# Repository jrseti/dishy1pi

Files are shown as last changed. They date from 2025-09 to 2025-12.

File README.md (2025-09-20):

# dishy1pi
Satellite dish motor control for Raspberry Pi, hardware and software

This project was developed in Windows 11 with Python 3.12.

## Prerequisites

It is suggested to create a Python3 virtual environment for this project. Here is how:

- From the project root directory "python3 -m venv venv"
- .\venv\Scripts\activate (Note: this command will be a bit different on Linux or MacOS)

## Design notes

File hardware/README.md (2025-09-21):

# Hardware Projects for Dishy1Pi

This directory contains hardware projects and designs related to the Dishy1Pi, a Raspberry Pi Hat tocontrol motors and encoders for a satellite dish.

## Projects

- **Dishy1Pi**: The main project, a Raspberry Pi Hat designed to control motors and encoders for a satellite dish. It includes schematics, PCB layouts, and bill of materials (BOM).

- **power-supply**: A project focused on designing a power supply unit for the Dishy1Pi, ensuring it can provide the necessary voltage and current for operation.

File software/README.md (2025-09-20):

# Software for the Dish Controller

Nothing here yet. This will be the source code of the software that runs on the RaspberryPi Hat. Probably a mixture of C and Python.

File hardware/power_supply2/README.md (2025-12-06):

# Power Supply circuit based on the MP2322 Buck Chip
This is a simple PCB to test creating several voltages that are used on the Dishy1Pi PCB. Once this cirction is tested as working, the relevant schematic parts will be moved over to the DishyPi1 schematic. The voltages needed are:
- 12V to power each of the 2 encoders. This voltage is supplied from an external power supply and protected by a PTC fuse on the Dishy1Pi PCB. Also reverse polatiry protected.
- 5V to power the logic circuity on the Dishy1Pi PCB.

The buck chip is the MP2322 from Monolithic Power Systems. Link to datasheet: https://www.monolithicpower.com/en/documentview/productdocument/index/version/1/document_type/Datasheet/lang/en/sku/MP2322

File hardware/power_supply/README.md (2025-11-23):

# Power Supply

This is a simple PCB to test creating several voltages that are used on the Dishy1Pi PCB. Once this cirction is tested as working, the relevant schematic parts will be moved over to the DishyPi1 schematic. The voltages needed are:
- 12V to power each of the 2 encoders. This voltage is supplied from an external power supply and protected by a PTC fuse on the Dishy1Pi PCB. Also reverse polatiry protected.
- 5V to power the logic circuity on the Dishy1Pi PCB. This voltage is generated on this power supply PCB from the 12-24V input voltage using a buck converter.

I need to learn how to design a power supply for a PCB board and get some experience with power supply design.

Project Goals:
- Design a power supply PCB that can take an input voltage range of 12-24VDC
- Output a stable 5VDC at up to 1A
Output clean 12V for each of the 2 encoders
- Create a schematic and PCB layout for the power supply that can be manufactured by JLCPCB.
- Get a board manufactureed and assembled by JLCPCB and test it, verify it works.
- Move the design of the power circuit to the dishy1pi project.

KiCad will be used for this project.

Used TI's WEBENCH Power Designer to design the power supply around the TPS561201DDCR buck converter IC. Link: https://webench.ti.com/power-designer/

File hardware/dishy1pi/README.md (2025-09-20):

# Dishy1Pi Hardware

The hardware part of the Dishy1Pi project is a Raspberry Pi Hat board which interfaces the Raspberry Pi GPIO pins with the satellite dish motor controllers, encoders, and various sensors. An important aspect of this board is that the Raspberry Pi is optically isolated from the hardware connected to the satellite dish.

Although this project is tailored to controlling a satellite dish, it can also be used for controlling other motor control systems that require isolation and encoder feedback.

## Parts Library

The PCB will be assembled by JCLPCB. The project will require parts number identification to be compatible with LCSC part numbers. See [Library README](libs/README.md)

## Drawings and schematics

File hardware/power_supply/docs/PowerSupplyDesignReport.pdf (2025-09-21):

## WEBENCH ® Design Report

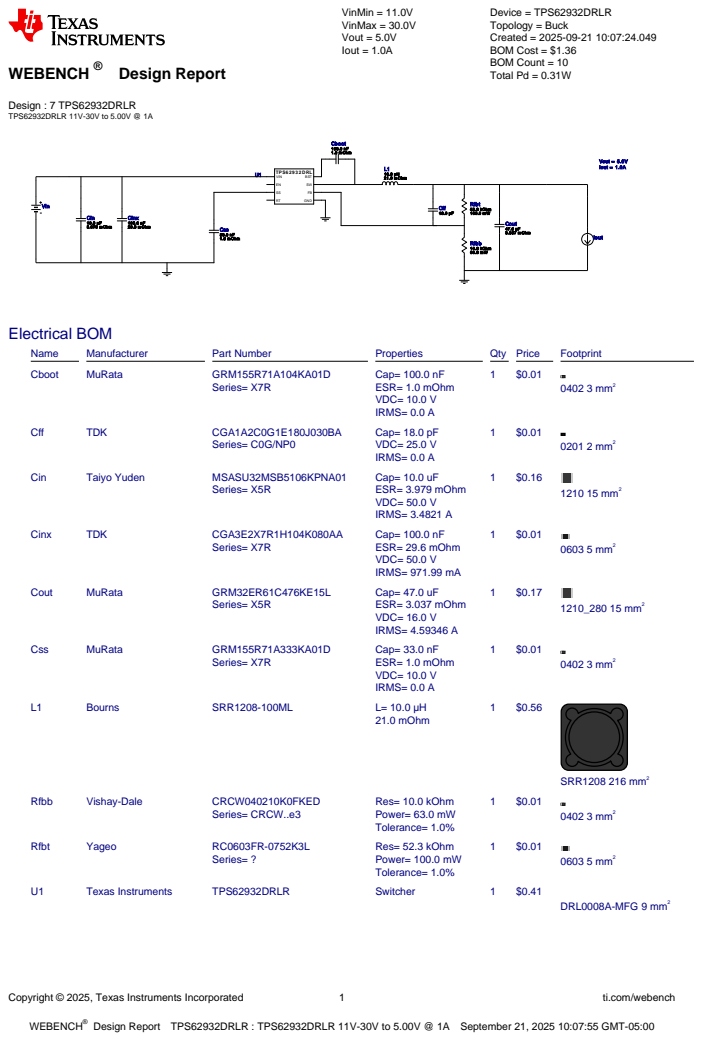
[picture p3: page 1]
Copyright © 2025, Texas Instruments Incorporated; ti.com/webench; WEBENCH®; Design : 7 TPS62932DRLR TPS62932DRLR 11V-30V to 5.00V @ 1A; VinMin = 11.0V VinMax = 30.0V Vout = 5.0V Iout = 1.0A; Device = TPS62932DRLR Topology = Buck Created = 2025-09-21 10:07:24.049 BOM Cost = $1.36 BOM Count = 10 Total Pd = 0.31W; Cout 47.0 µF 3.037 m Ohm Css 33.0 nF 1.0 m Ohm; L1 10.0 µH 21.0 m Ohm; Vout = 5.0V Iout = 1.0A; Rfbb 10.0 kOhm 63.0 m W; Rfbt 52.3 kOhm; Cin 10.0 µF 3.979 m Ohm; Cff 18.0 pF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

Design Report TPS62932DRLR : TPS62932DRLR 11V-30V to 5.00V @ 1A September 21, 2025 10:07:55 GMT-05:00

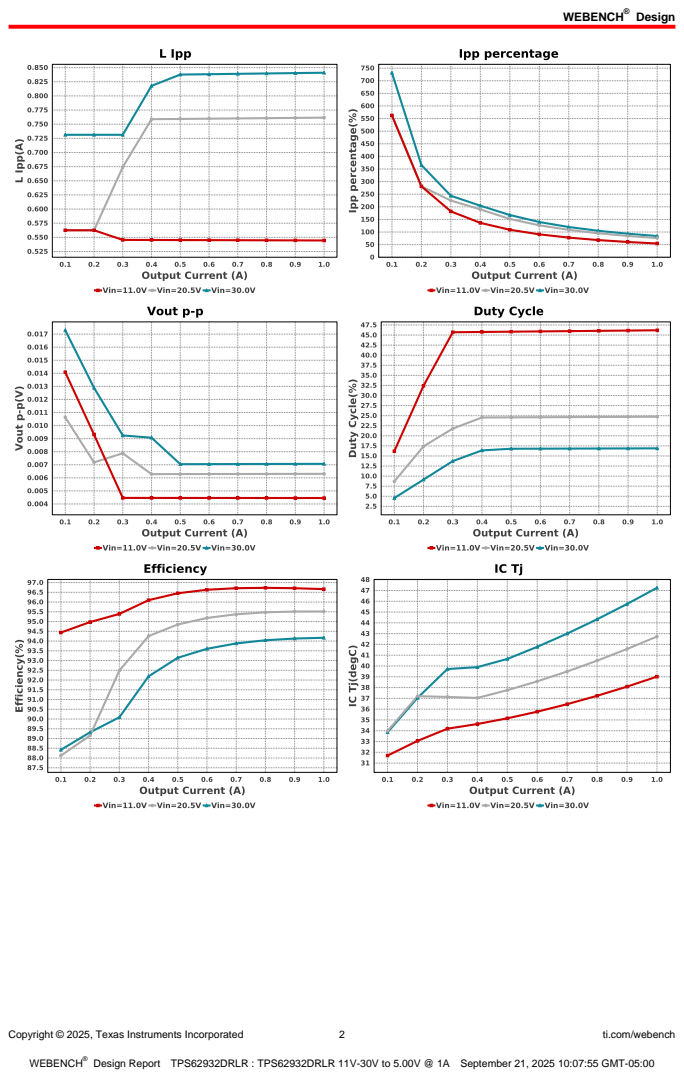
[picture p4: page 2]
Design; Copyright © 2025, Texas Instruments Incorporated; ti.com/webench

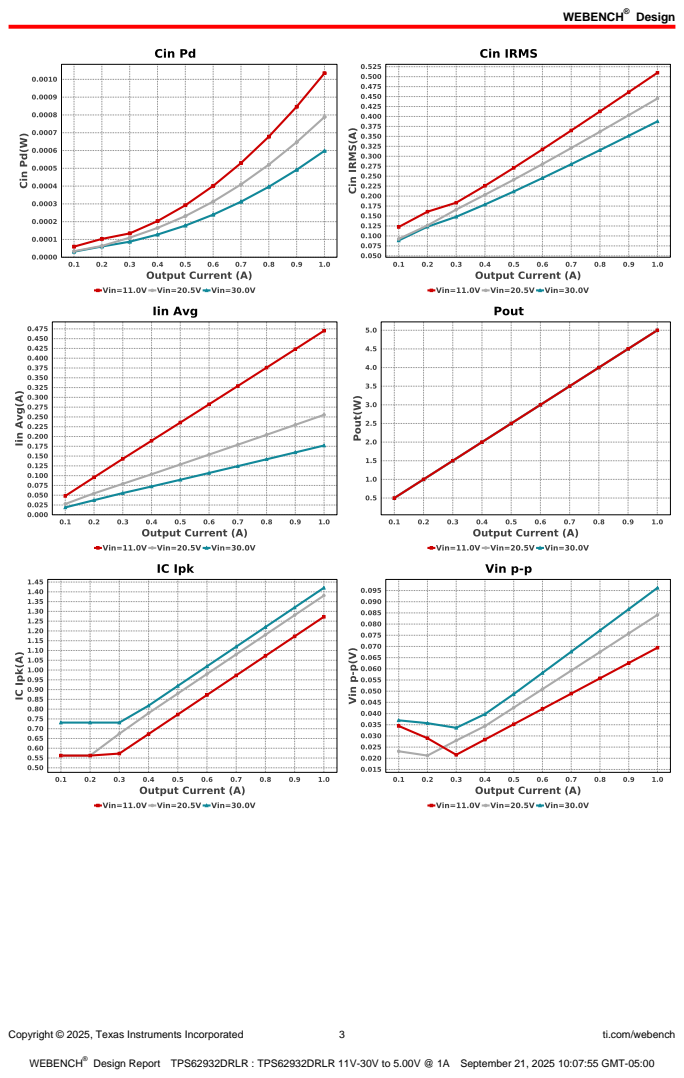
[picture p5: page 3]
Copyright © 2025, Texas Instruments Incorporated; ti.com/webench

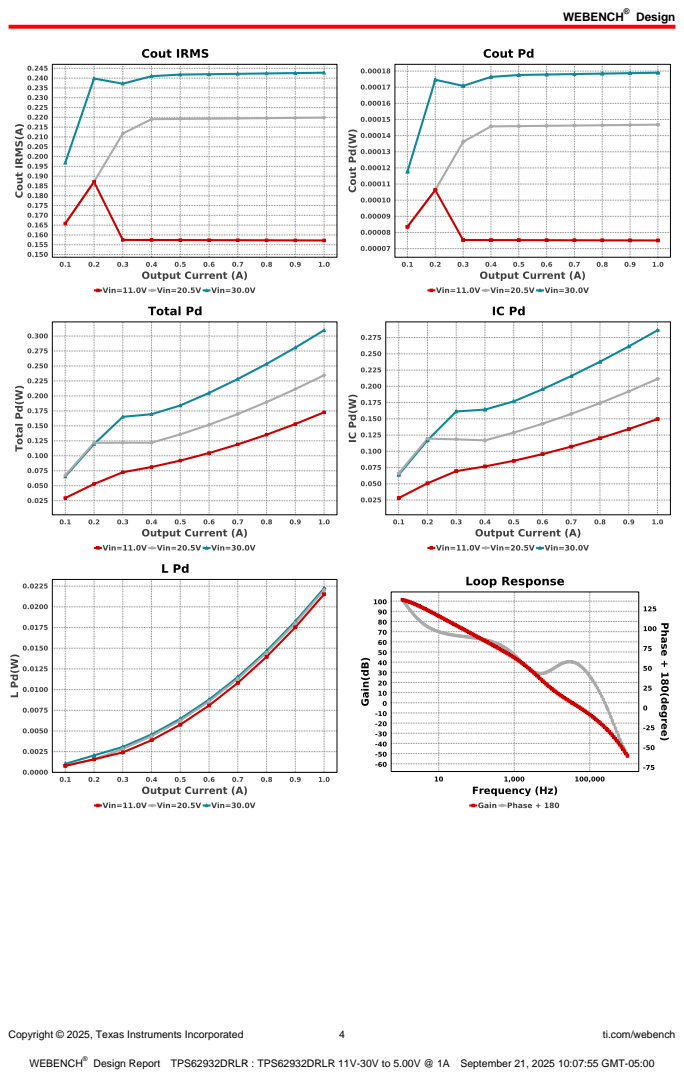
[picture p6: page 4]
Copyright © 2025, Texas Instruments Incorporated; ti.com/webench

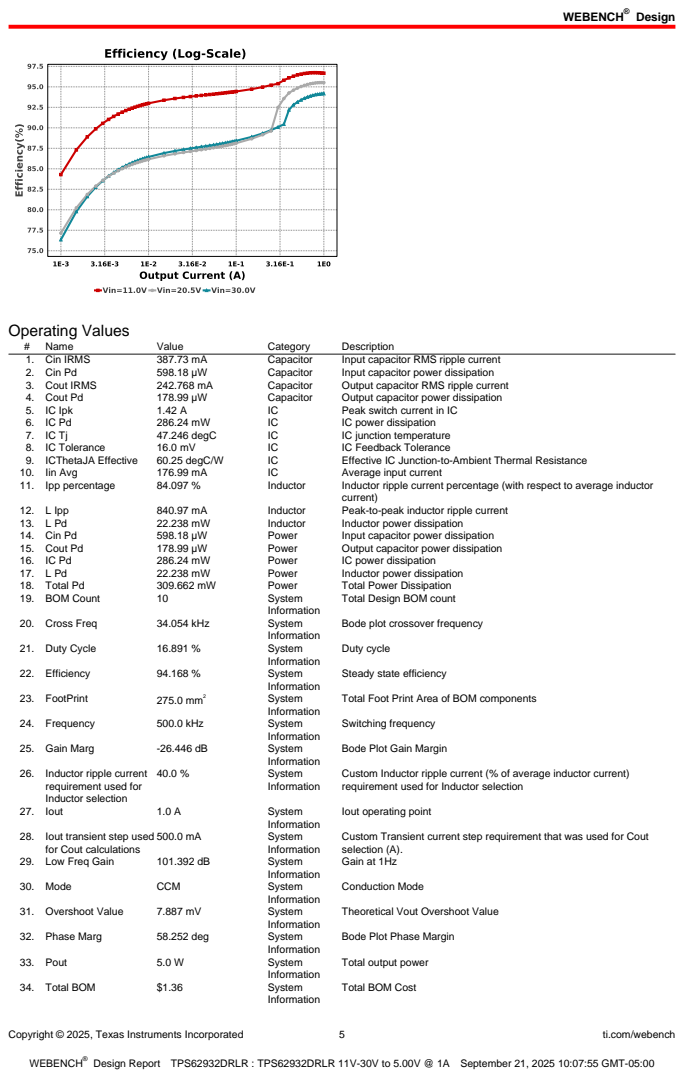
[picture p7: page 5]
Copyright © 2025, Texas Instruments Incorporated; ti.com/webench; Operating Values; Name; Value; Category; Description; 1. Cin IRMS; Capacitor; Input capacitor RMS ripple current; 2. Cin Pd; Input capacitor power dissipation; 3. Cout IRMS; Output capacitor RMS ripple current; 4. Cout Pd; Output capacitor power dissipation; 5. IC Ipk; Peak switch current in IC; IC power dissipation; 47.246 degC; IC junction temperature; 8. IC Tolerance; IC Feedback Tolerance; 9. ICThetaJA Effective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

Total Design BOM count

Bode plot crossover frequency

Steady state efficiency

Total Foot Print Area of BOM components

Bode Plot Gain Margin

26. Inductor ripple current
requirement used for
Inductor selection

Custom Inductor ripple current (% of average inductor current)
requirement used for Inductor selection

Iout operating point

28. Iout transient step used
for Cout calculations

Custom Transient current step requirement that was used for Cout
selection (A).
Gain at 1Hz

Theoretical Vout Overshoot Value

Bode Plot Phase Margin

Total output power

Total BOM Cost

Copyright © 2025, Texas Instruments Incorporated | 6 | ti.com/webench
# | Name | Value | Category | Description

35. Undershoot Value | 27.869 mV | System
| | | Information | Theoretical Vout Undershoot Value
36. Vin | 30.0 V | System
| | | Information | Vin operating point
37. Vin p-p | 96.207 mV | System
| | | Information | Peak-to-peak input voltage
38. Vout | 5.0 V | System
| | | Information | Operational Output Voltage
39. Vout Actual | 4.984 V | System
| | | Information | Vout Actual calculated based on selected voltage divider resistors
40. Vout Ripple
| requirement used for Cout calculations | 1.0 % | System Information | Custom maximum output ripple requirement that was used for Cout selection(% of Vout).
41. Vout Tolerance | 3.73 % | System
| | | Information | Vout Tolerance based on IC Tolerance (no load) and voltage divider resistors if applicable
42. Vout p-p | 7.071 mV | System
| | | Information | Peak-to-peak output ripple voltage
43. Vout transient
| requirement used for Cout calculations | 3.0 % | System Information | Custom Transient voltage change requirement that was used for Cout selection (% of Vout).

## Design Inputs

Name | Value | Description
Iout | 1.0 | Maximum Output Current
VinMax | 30.0 | Maximum input voltage
VinMin | 11.0 | Minimum input voltage
Vout | 5.0 | Output Voltage
| base_pn | | TPS62932 | Base Product Number
source | DC | Input Source Type
Ta | 30.0 | Ambient temperature


Copyright © 2025, Texas Instruments Incorporated | 7 | ti.com/webench

## Assembly

## Component Testing

Some published data on components in datasheets such as Capacitor ESR and Inductor DC resistance is based on conservative values that will guarantee that the components always exceed the specification. For design purposes it is usually better to work with typical values. Since this data is not always available it is a good practice to measure the Capacitance and ESR values of Cin and Cout, and the inductance and DC resistance of L1 before assembly of the board. Any large discrepancies in values should be electrically simulated in WEBENCH to check for instabilities and thermally simulated in WebTHERM to make sure critical temperatures are not exceeded.
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

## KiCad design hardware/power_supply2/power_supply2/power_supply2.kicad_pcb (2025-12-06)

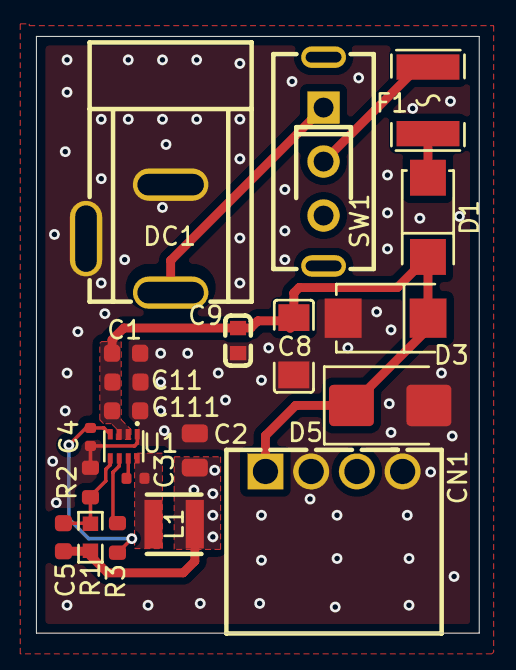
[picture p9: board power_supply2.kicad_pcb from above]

Board: 4 copper layers, 24.6 x 33.1 mm, 21 parts (0 on the bottom side), 11 nets.

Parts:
C1: 100nF; C_0603
C2: 22uF; C_0805
C3: 22pF; C_0402
C4: 1uF; C_0402
C5: 22pF; C_0603
C8: 47uF; C1206
C9: 100nF; C0603
C11, C111: 10uF; C_0603
CN1: KF2EDGR-2.54-4P; CONN-TH_4P-P2.54_KF2EDGR-2.54-4P
D1: SS34; SMA_L4.3-W2.6-LS5.2-RD
D3: SMBJ18A; SMB_L4.6-W3.6-LS5.3-RD
D5: SMBJ16A; D_SMB
DC1: DC-005-2.5A-2.0; CONN-TH_DC-005-2.5A-2.0
F1: 1812L110/33MR; F1812
L1: 4.7uH; IND-SMD_L3.0-W3.0-1
R1: 1.62K; R0603
R2: 220Ω; R_0603
R3: 200kΩ; R_0603
SW1: SS-12F49-G050; SW-TH_SS-12F45-GXXX
U1: MP2322GQH-Z; QFN-8_L2.0-W1.5-P0.50-BL

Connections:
/5V: C2.1, C5.1, CN1.3, L1.2, R1.1
/12V_IN: DC1.1, SW1.1
/12V_PROT: C1.1, C8.1, C9.1, C11.1, C111.1, CN1.1, D1.1 (K), D3.1 (K), D5.1, U1.2 (IN), U1.3 (EN)
GND: C1.2, C2.2, C4.2, C8.2, C9.2, C11.2, C111.2, CN1.2, CN1.4, D3.2 (A), D5.2, DC1.2, DC1.3, R2.2, U1.1 (GND)
unnamed: D1.2 (A), F1.2
unnamed: F1.1, SW1.2
unnamed: C3.1, U1.7 (BST)
unnamed: C5.2, R1.2, R2.1, U1.5 (FB)
unnamed: R3.1, U1.6 (PG)
unnamed: C3.2, L1.1, U1.8 (SW)
unnamed: C4.1, R3.2, U1.4 (VCC)

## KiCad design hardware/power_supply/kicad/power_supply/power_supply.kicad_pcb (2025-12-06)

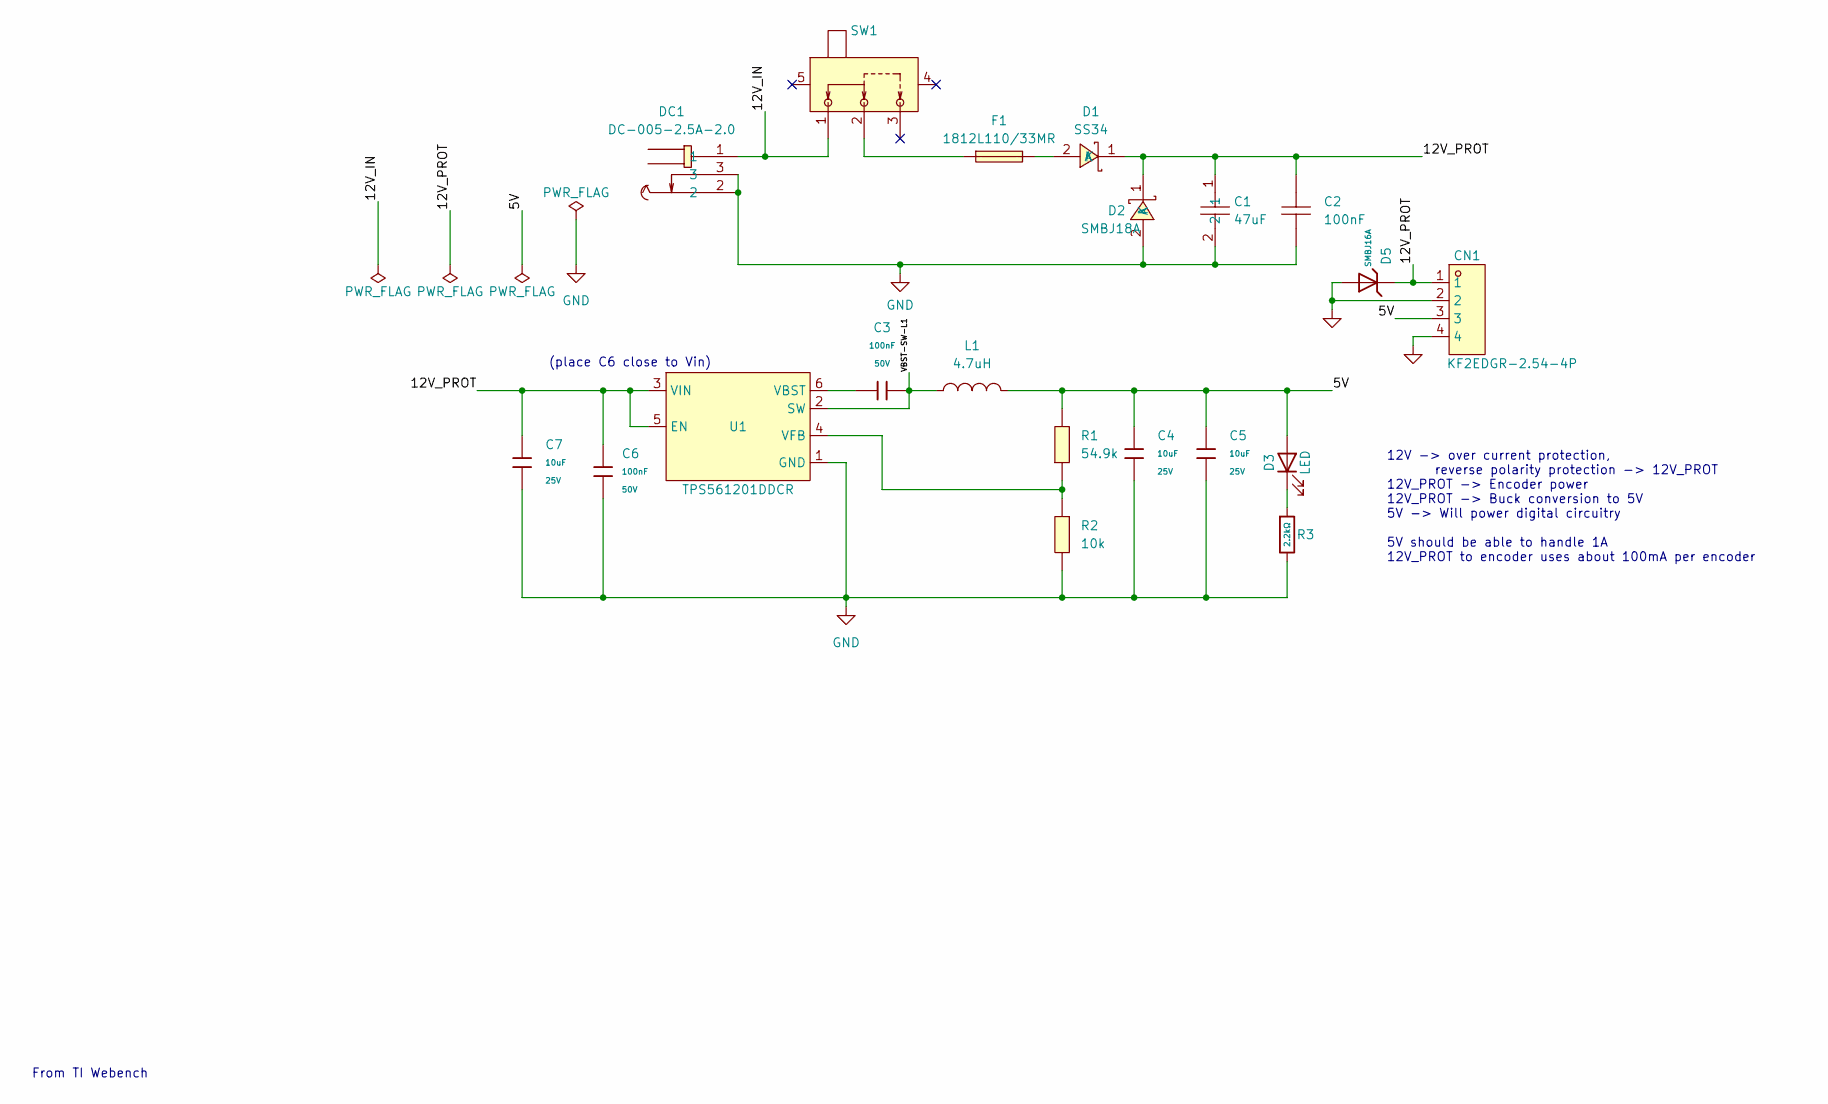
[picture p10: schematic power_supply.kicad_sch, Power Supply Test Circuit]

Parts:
C1: 47uF; C1206; LCSC Part C403725
C2: 100nF; C0603; LCSC Part C14663
C3: 100nF; C_0402; Voltage Rated 50V; Tolerance ±10%; Part CL05B104KB54PNC; LCSC C307331
C4, C5, C7: 10uF; C_0805; Voltage Rated 25V; Tolerance ±10%; Part CL21A106KAYNNNE; LCSC C15850
C6: 100nF; C_0805; Voltage Rated 50V; Tolerance ±10%; Part CC0805KRX7R9BB104; LCSC C49678
CN1: KF2EDGR-2.54-4P; CONN-TH_4P-P2.54_KF2EDGR-2.54-4P; LCSC Part C577596
D1: SS34; SMA_L4.3-W2.6-LS5.2-RD; LCSC Part C8678
D2: SMBJ18A; SMB_L4.6-W3.6-LS5.3-RD; LCSC Part C2965323
D3: LED; LED_1206_3216Metric; LCSC Part C5264252
D5: SMBJ16A; D_SMB; Part SMBJ16A; LCSC C19077571
DC1: DC-005-2.5A-2.0; CONN-TH_DC-005-2.5A-2.0; LCSC Part C319099
F1: 1812L110/33MR; F1812; LCSC Part C142747
L1: 4.7uH; IND-SMD_L3.0-W3.0-1; LCSC Part C7427089
R1: 54.9k; R0603; LCSC Part C23077
R2: 10k; R0603; LCSC Part C25804
R3: 2.2kΩ; R_0402; Overload Voltage (Max) 50V; Tolerance ±1%; Part 0402WGF2201TCE; LCSC C25879
SW1: SS-12F49-G050; SW-TH_SS-12F45-GXXX; LCSC Part C2876010
U1: TPS561201DDCR; SOT-23-6_L2.9-W1.6-P0.95-LS2.8-BR; LCSC Part C220433

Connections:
/5V: C4.1, C5.1, CN1.3, D3.2 (A), L1.2, R1.2
/12V_IN: DC1.1, SW1.1
/12V_PROT: C1.1, C2.1, C6.1, C7.1, CN1.1, D1.1 (K), D2.1 (K), D5.1, U1.3 (VIN), U1.5 (EN)
/VBST-SW-L1: C3.2, L1.1, U1.2 (SW)
GND: C1.2, C2.2, C4.2, C5.2, C6.2, C7.2, CN1.2, CN1.4, D2.2 (A), D5.2, DC1.2, DC1.3, R2.2, R3.2, U1.1 (GND)
unnamed: D1.2 (A), F1.2
unnamed: D3.1 (K), R3.1
unnamed: F1.1, SW1.2
unnamed: C3.1, U1.6 (VBST)
unnamed: R1.1, R2.1, U1.4 (VFB)

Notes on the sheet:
From TI Webench
(place C6 close to Vin)
12V -> over current protection, reverse polarity protection -> 12V_PROT 12V_PROT -> Encoder power 12V_PROT -> Buck conversion to 5V 5V -> Will power digital circuitry 5V should be able to handle 1A 12V_PROT to encoder uses about 100mA per encoder

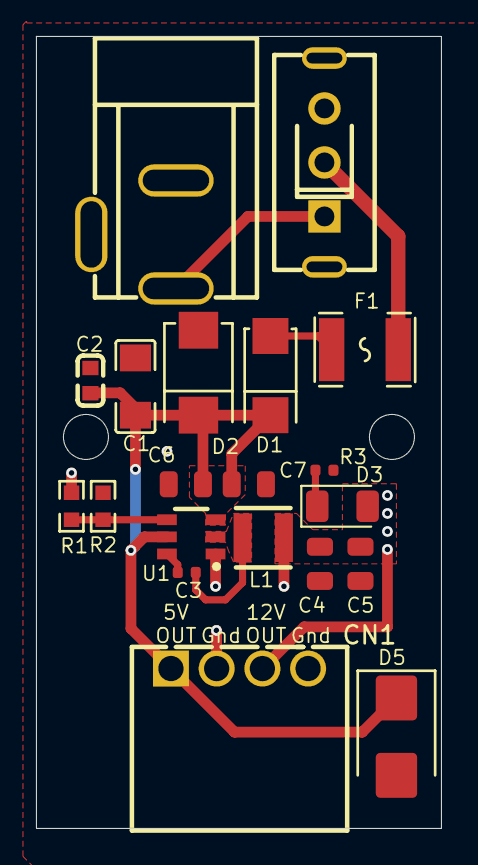
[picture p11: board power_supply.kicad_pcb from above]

Board: 4 copper layers, 22.5 x 44.0 mm, 20 parts (0 on the bottom side), 10 nets.

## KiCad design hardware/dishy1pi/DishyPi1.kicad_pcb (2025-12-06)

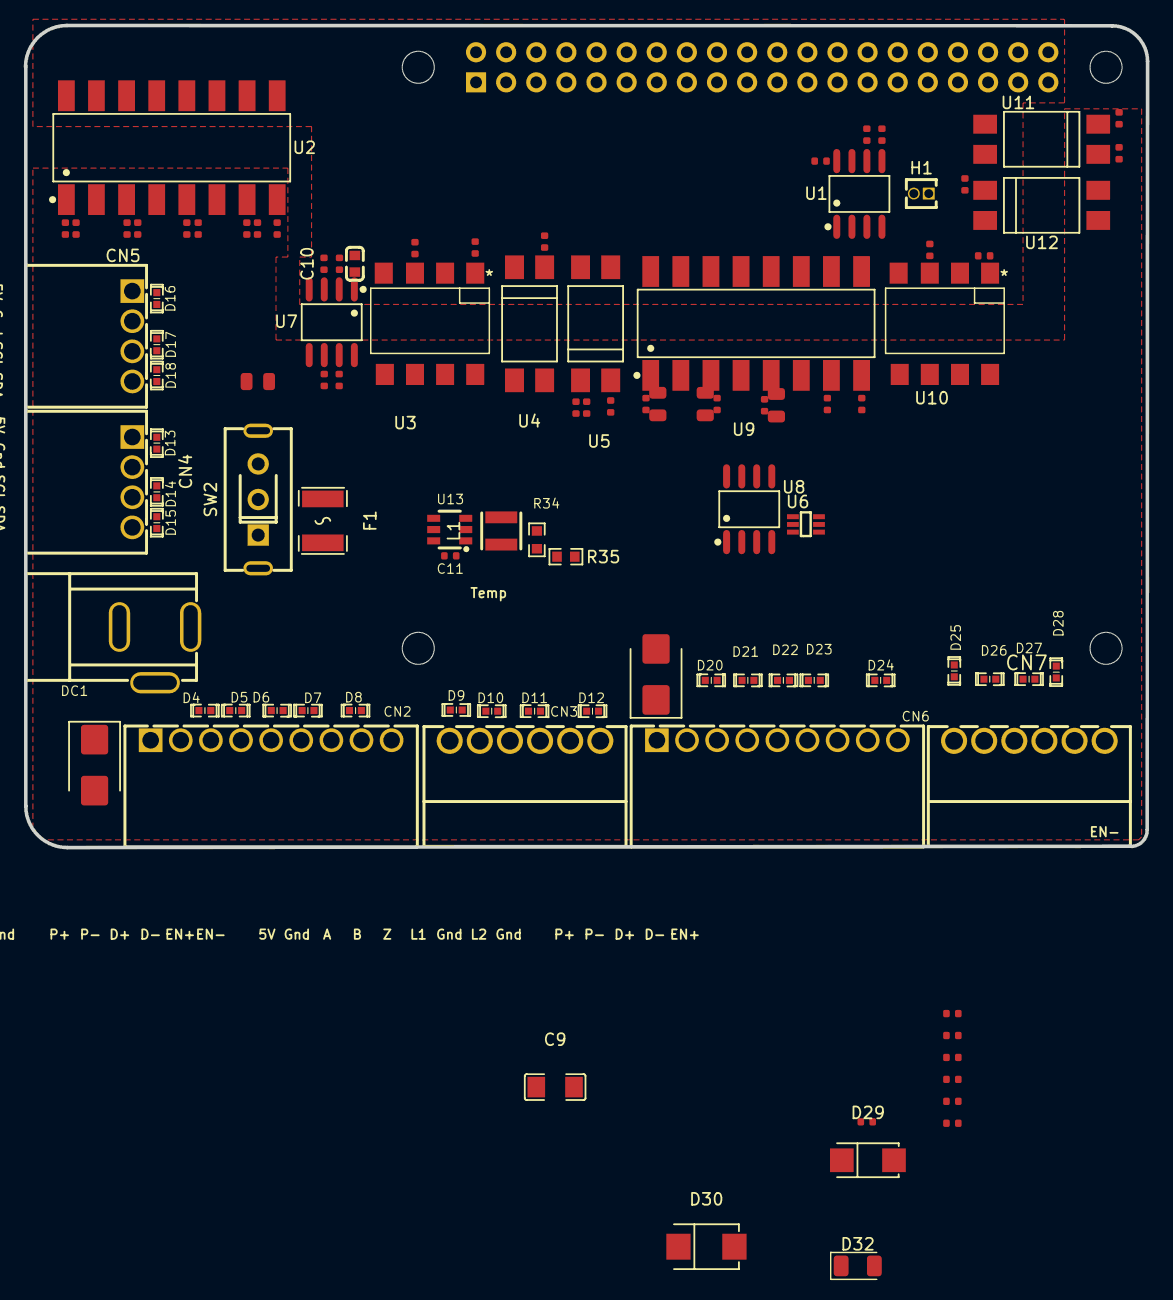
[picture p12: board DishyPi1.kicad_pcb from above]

Board: 4 copper layers, 94.6 x 69.3 mm, 106 parts (1 on the bottom side), 67 nets, no tracks yet.

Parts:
C3, C5, C6, C7, C8, C11: 100nF; C_0402
C4: 100pF; C_0402
C9: 47uF; C1206
C10: 100nF; C0603
C12, C13, C14: 10uF; C_0805
C15: 100nF; C_0805
CN2, CN6: KF2EDGR-2.54-9P; CONN-TH_9P-P2.54_KF2EDGR-2.54-9P
CN3, CN7: KF2EDGR-2.54-6P; CONN-TH_KF2EDGR-2.54-6P
CN4, CN5: KF2EDGR-2.54-4P; CONN-TH_4P-P2.54_KF2EDGR-2.54-4P
D4, D5, D6, D7, D8, D9, D10, D11, D12, D13, D14, D15, D16, D17, D18, D20, D21, D22, D23, D24, D25, D26, D27, D28: TPESD0402G05V; D0402-BI
D29: SS34; SMA_L4.3-W2.6-LS5.2-RD
D30: SMBJ18A_C78412; SMB_L4.6-W3.6-LS5.3-RD
D32: LED; LED_1206_3216Metric
D33, D34: SMBJ16A; D_SMB
DC1: DC-005-2.5A-2.0; CONN-TH_DC-005-2.5A-2.0
F1: 1812L110/33MR; F1812
H1: 1.27MM/1*2P; HDR-TH_2P-P1.27-V-M
J1: Conn_02x20_Odd_Even; PinSocket_2x20_P2.54mm_Vertical
L1: 4.7uH; IND-SMD_L3.0-W3.0-1
MH1, MH2, MH3, MH4: MountingHole_2.7mm_M2.5
R2, R3: 3.9kΩ; R_0402
R4, R6, R8, R12, R13, R14, R21, R23, R25, R29, R30, R31: 1kΩ; R_0402
R5, R7, R9, R22, R24, R26: 10kΩ; R_0402
R10, R27: 220Ω; R_0402
R11, R16, R28, R33: 22kΩ; R_0402
R15, R32: 470Ω; R_0402
R17, R18, R19, R20: 4.7kΩ; R_0402
R34: 54.9k; R0603
R35: 10k; R0603
R36: 2.2kΩ; R_0402
SW2: SS-12F49-G050; SW-TH_SS-12F45-GXXX
U1: CAT24C256WI-GT3; SOIC-8_L4.9-W3.9-P1.27-LS6.0-BL
U2, U9: LTV-847S; SMD-16_L20.0-W6.5-P2.54-LS10.2-BL
U3, U10: LTV-827S-TA1; LTV827S-TA1
U4, U5, U11, U12: LTV-817S-TA1; LTV817S
U6: LTC4311ISC6#TRPBF; SC-70-6_L2.2-W1.3-P0.65-LS2.2-BL
U7: ISO1540DR; SOIC-8_L4.9-W3.9-P1.27-LS6.0-BL
U8: LM75BIMX-5/NOPB; SOIC-8_L4.9-W3.9-P1.27-LS6.0-BL
U13: TPS561201DDCR; SOT-23-6_L2.9-W1.6-P0.95-LS2.8-BR

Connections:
12V_PROT: C9.1, C10.1, C14.1, C15.1, CN2.1, CN6.1, D29.1 (K), D30.1 (K), D33.1, D34.1, U13.3 (VIN), U13.5 (EN)
+3.3V: C3.1, C6.1, H1.1, J1.1, J1.17, R2.1, R3.1, R17.1, R18.1, U1.8 (VCC), U7.1 (VCC1)
+5V: C5.1, C7.1, C8.1, C12.1, C13.1, CN3.1, CN3.3, CN3.5, CN4.1, CN5.1, CN7.1, CN7.3, CN7.5, D9.1 (K), D13.1 (K), D16.2 (A), D25.1 (K), D32.2 (A), L1.2, R4.1, R5.1, R6.1, R7.1, R8.1, R9.1, R10.1, R15.1, R16.2, R19.1, R20.1, R21.1, R22.1, R23.1, R24.1, R25.1, R26.1, R27.1, R28.2, R32.1, R33.2, R34.2, U6.1 (VCC), U6.3 (ENABLE), U7.8 (VCC2), U8.7 (A0), U8.8 (+VS)
/12v_in/12V_IN: DC1.1, SW2.1
/12v_in/VBST-SW-L1: C11.2, L1.1, U13.2 (SW)
/I2C/SCL: CN4.3, CN5.3, D14.1 (K), D17.2 (A), R20.2, U6.4 (BUS2), U7.6 (SCL2), U8.2 (SCL)
/I2C/SDA: CN4.4, CN5.4, D15.1 (K), D18.2 (A), R19.2, U6.6 (BUS1), U7.7 (SDA2), U8.1 (SDA)
/ID_SCL: J1.28, R2.2, U1.6 (SCL)
/ID_SDA: J1.27, R3.2, U1.5 (SDA)
/IO/DIR-: CN3.4, D11.1 (K), U3.8
/IO/ENC_A: CN2.3, D4.1 (K), R9.2, U2.2 (CAT1)
/IO/ENC_B: CN2.4, D5.1 (K), R7.2, U2.4 (CAT2)
/IO/ENC_Z: CN2.5, D6.1 (K), R5.2, U2.6 (CAT3)
/IO/LIM_1: CN2.6, D7.1 (K), R11.1, U2.8 (CAT4)
/IO/LIM_2: CN2.8, D8.1 (K), R16.1, U5.2
/IO/MF-: CN3.6, D12.1 (K), U4.4
/IO/PUL-: CN3.2, D10.1 (K), U3.6
/io2/DIR-: CN7.4, D27.1 (K), U10.6
/io2/ENC_A: CN6.3, D20.1 (K), R26.2, U9.2 (CAT1)
/io2/ENC_B: CN6.4, D21.1 (K), R24.2, U9.4 (CAT2)
/io2/ENC_Z: CN6.5, D22.1 (K), R22.2, U9.6 (CAT3)
/io2/LIM_1: CN6.6, D23.1 (K), R28.1, U9.8 (CAT4)
/io2/LIM_2: CN6.8, D24.1 (K), R33.1, U12.2
/io2/MF-: CN7.6, D28.1 (K), U11.4
/io2/PUL-: CN7.2, D26.1 (K), U10.8
A_DIR/19: J1.35, R30.1
A_ENC_A/5: J1.29, U9.16 (COL1)
A_ENC_B/6: J1.31, U9.14 (COL2)
A_ENC_Z/26: J1.37, U9.12 (COL3)
A_LIM_1/12: J1.32, U9.10 (COL4)
A_LIM_2/21: J1.40, U12.4
A_MF/20: J1.38, R31.1
A_PUL/13: J1.33, R29.1
E_DIR/23: J1.16, R12.1
E_ENC_A/17: J1.11, U2.16 (COL1)
E_ENC_B/22: J1.13, U2.14 (COL2)
E_ENC_Z/27: J1.15, U2.12 (COL3)
E_LIM_1/25: J1.22, U2.10 (COL4)
E_LIM_2/16: J1.36, U5.4
E_MF/24: J1.18, R14.1
E_PUL/18: J1.12, R13.1
GNDIO: C4.2, C5.2, C7.2, C8.2, C9.2, C10.2, C12.2, C13.2, C14.2, C15.2, CN2.2, CN2.7, CN2.9, CN4.2, CN5.2, CN6.2, CN6.7, CN6.9, D4.2 (A), D5.2 (A), D6.2 (A), D7.2 (A), D8.2 (A), D9.2 (A), D10.2 (A), D11.2 (A), D12.2 (A), D13.2 (A), D14.2 (A), D15.2 (A), D16.1 (K), D17.1 (K), D18.1 (K), D20.2 (A), D21.2 (A), D22.2 (A), D23.2 (A), D24.2 (A), D25.2 (A), D26.2 (A), D27.2 (A), D28.2 (A), D30.2 (A), D33.2, D34.2, DC1.2, DC1.3, R11.2, R35.2, R36.2, U3.5, U3.7, U4.3, U6.2 (GND), U6.5 (GND), U7.5 (GND2), U8.4 (GND), U8.5 (A2), U8.6 (A1), U10.5, U10.7, U11.3, U13.1 (GND)
GNDPI: C3.2, C6.2, J1.6, J1.9, J1.14, J1.20, J1.25, J1.30, J1.34, J1.39, U1.1 (A0), U1.2 (A1), U1.3 (A2), U1.4 (VSS), U2.9 (EM4), U2.11 (EM3), U2.13 (EM2), U2.15 (EM1), U3.2, U3.4, U4.2, U5.3, U7.4 (GND1), U9.9 (EM4), U9.11 (EM3), U9.13 (EM2), U9.15 (EM1), U10.2, U10.4, U11.2, U12.3
unnamed: D29.2 (A), F1.2
unnamed: D32.1 (K), R36.1
unnamed: F1.1, SW2.2
unnamed: R12.2, U3.1
unnamed: R13.2, U3.3
unnamed: R14.2, U4.1
unnamed: R15.2, U5.1
unnamed: R29.2, U10.1
unnamed: R30.2, U10.3
unnamed: R31.2, U11.1
unnamed: R32.2, U12.1
unnamed: H1.2, U1.7 (WP)
unnamed: R8.2, U2.1 (AN1)
unnamed: R6.2, U2.3 (AN2)
unnamed: R4.2, U2.5 (AN3)
unnamed: C4.1, R10.2, U2.7 (AN4)
unnamed: R25.2, U9.1 (AN1)
unnamed: R23.2, U9.3 (AN2)
unnamed: R21.2, U9.5 (AN3)
unnamed: R27.2, U9.7 (AN4)
unnamed: C11.1, U13.6 (VBST)
unnamed: R34.1, R35.1, U13.4 (VFB)
PI_SCL: J1.5, R17.2, U7.3 (SCL1)
PI_SDA: J1.3, R18.2, U7.2 (SDA1)

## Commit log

2025-09-20 Added hardware KiCad project
    [DishyPi1.kicad_pcb, DishyPi1.kicad_sch, i2c.kicad_sch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]
2025-09-21 Removed ignoring kicad_prl
2025-09-21 Moved kicad files into new dishy1pi dir
    [DishyPi1.kicad_pcb, DishyPi1.kicad_sch, i2c.kicad_sch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]
2025-09-21 Moves kicad files into dishy1pi dir
    [DishyPi1.kicad_pcb, DishyPi1.kicad_sch, i2c.kicad_sch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]
2025-09-21 Added power_supply
2025-09-21 Fleshed out the BOM
2025-09-21 Updated BOM
2025-09-28 Parts place in PCB layout
    [DishyPi1.kicad_pcb, DishyPi1.kicad_sch, i2c.kicad_sch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]
2025-09-30 Ground and Power planes placed
    [DishyPi1.kicad_pcb, DishyPi1.kicad_sch, i2c.kicad_sch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]
2025-11-23 Modifications based on first board assembly
    [DishyPi1.kicad_pcb, DishyPi1.kicad_sch, i2c.kicad_sch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]
2025-11-23 Firs PCB and scheamtic push
    [power_supply.kicad_pcb, power_supply.kicad_sch]
2025-11-23 Added pwr_12v_in.kicad_sch
    [pwr_12v_in.kicad_sch]
2025-11-23 Added power circuit to dishy schematic
    [DishyPi1.kicad_pcb, DishyPi1.kicad_sch, i2c.kicad_sch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]
2025-11-23 New PCB layout started
    [DishyPi1.kicad_pcb]
2025-12-06 Added 12V power input
    [DishyPi1.kicad_pcb, DishyPi1.kicad_sch, i2c.kicad_sch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]
2025-12-06 Little change
    [pwr_12v_in.kicad_sch]

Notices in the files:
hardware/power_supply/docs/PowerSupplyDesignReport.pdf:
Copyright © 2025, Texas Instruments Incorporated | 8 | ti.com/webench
